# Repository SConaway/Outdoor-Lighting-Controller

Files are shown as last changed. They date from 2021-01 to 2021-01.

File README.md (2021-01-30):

# Outdoor-Lighting-Controller

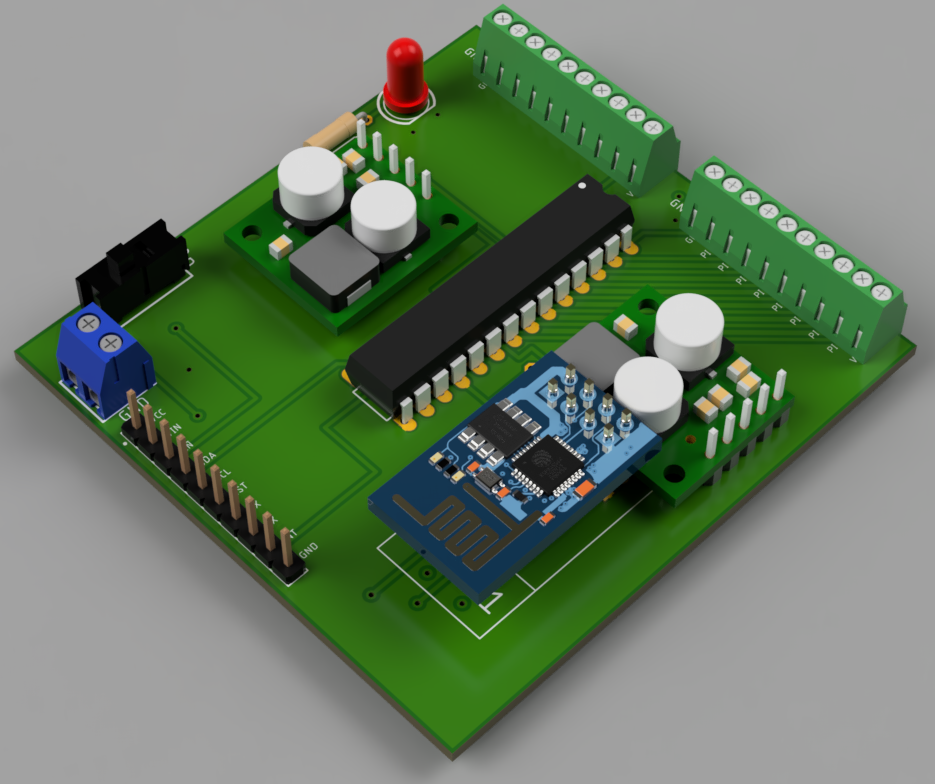
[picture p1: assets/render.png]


## Description

This is the hardware (PCB) and the software (ESPHome configuration) for a Home Assistant-based motion-lights controller. ESPHome is used to interface with Home Assistant, which is responsible for controlling the lights and motion alerts, etc.

## Instructions

1. Download the board files from GitHub Release.
2. Order the needed parts ([parts list below](#parts-list)).
    1. I used [JLCPCB](jlcpcb.com) for the PCB; it cost me $2 (+ shipping) for 5 boards.
3. Assemble all parts on the PCB.
4. [Install ESPHome](https://esphome.io/guides/getting_started_command_line.html#getting-started-with-esphome).
5. Create the secrets file from the template.
6. Connect the ESP-01 to the programming adapter.
7. Run `esphome lights.yaml compile` to compile the firmware.
8. Run `esphome lights.yaml upload` to upload the newly-compiled firmware.
9. Place the ESP-01 in the PCB, paying attention to the direction of where it points

## Parts List

-   1x Custom designed Circuit Board
-   1x 8 channel Relay Board (any generic one will work as long as it supports the needed power for your lights)
-   1x MCP23017 I2C IO Expander (**IC1**)
-   1x ESP-01 module with programmer (**U1**)
-   1x [D24V10F3 Voltage Regulator](https://www.pololu.com/product/2830) (powers ESP-01) (**VR1**)
-   1x [D24V10F5 Voltage Regulator](https://www.pololu.com/product/2831) (powers the motion sensors and MCP23017) (**VR2**)
-   _up to_ 8x PIR motion sensor
-   _up to_ 8x lights and a way to power them
    -   I used 12 Volt DC LED lights and a 120VAC --> 12VDC power supply
-   jumper wires to connect the Relay Board to the PCB (either individual wires or a 1x10 cable works)
-   2x 1x10 male header (**RELAYS and J1**)
-   1x 2x4 female header (alternatively, 2 rows of 1x4 would work too) (**socket for ESP-01**)
-   1x 2-pin 3.5mm screw terminal blocks (**J2**)
-   1x 10-pin 2.54mm (0.1 in) screw terminal blocks (**PIRS**)
-   1x SPDT on/off switch (**S1**)
-   1x 10K ohm resistor (**R1**)
-   _optional_: 1x LED (**D1**) and 1x 330 ohm resistor (**R2**)
-   1x 5K ohm resistor (I used a 5.2K ohm resistor I had lying around) (**R3**)
-   1x safe casing that prevents access to 120VAC power
-   1x server running Home Assistant for automating the lights in reaction to the motion sensors

## Notes

-   If ESPHome is not working properly (either not installing or not compiling), you can upload the binary in the GitHub Release using another uploading tool, such as `esptool`.
-   I tested this with ESPHome v1.15.3.

## [Schematics](assets/Schematic.pdf)

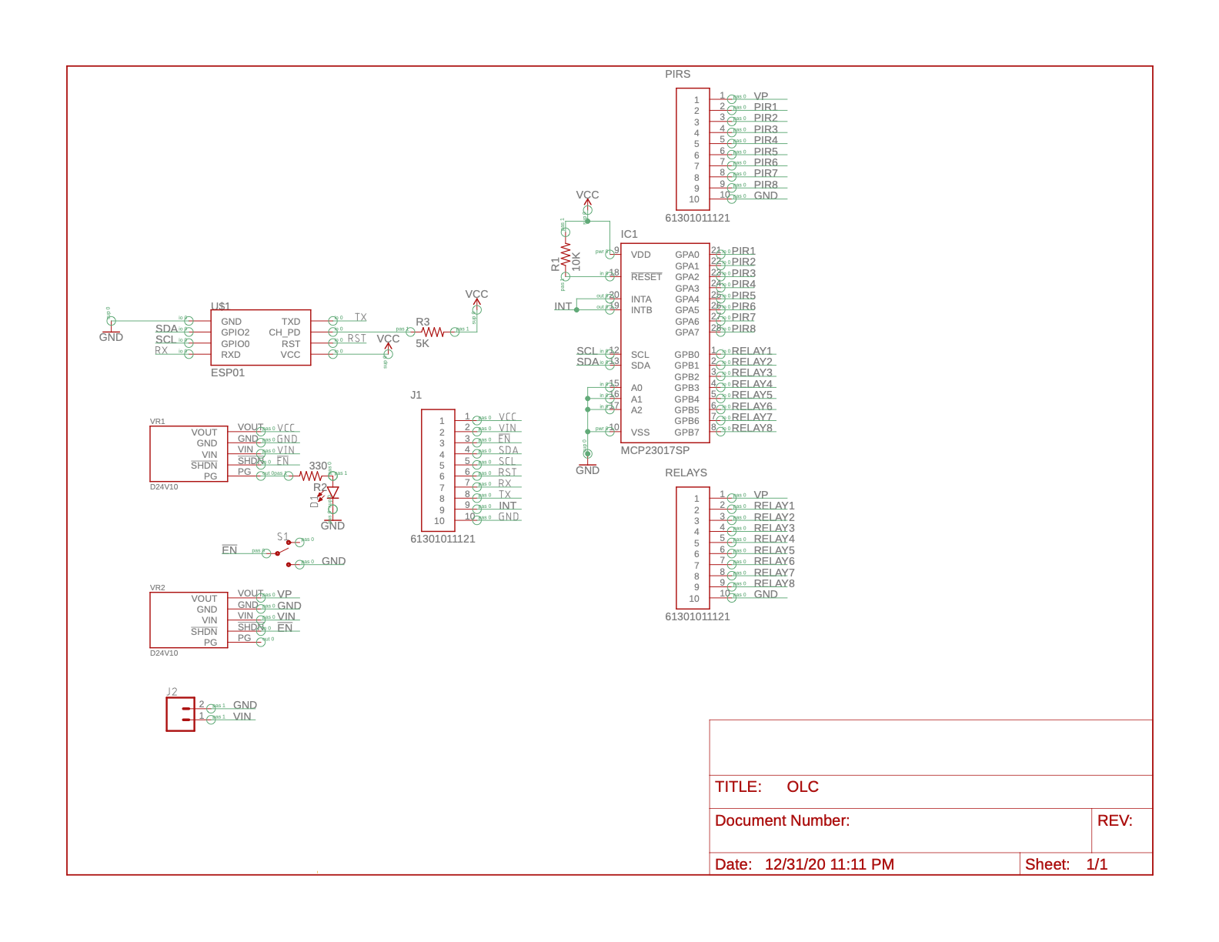
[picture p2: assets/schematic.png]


## Credits

-   [ESPHome](esphome.io)
-   [Home Assistant](home-assistant.io)
-   [Sparkfun's EAGLE libraries](https://github.com/sparkfun/SparkFun-Eagle-Libraries)

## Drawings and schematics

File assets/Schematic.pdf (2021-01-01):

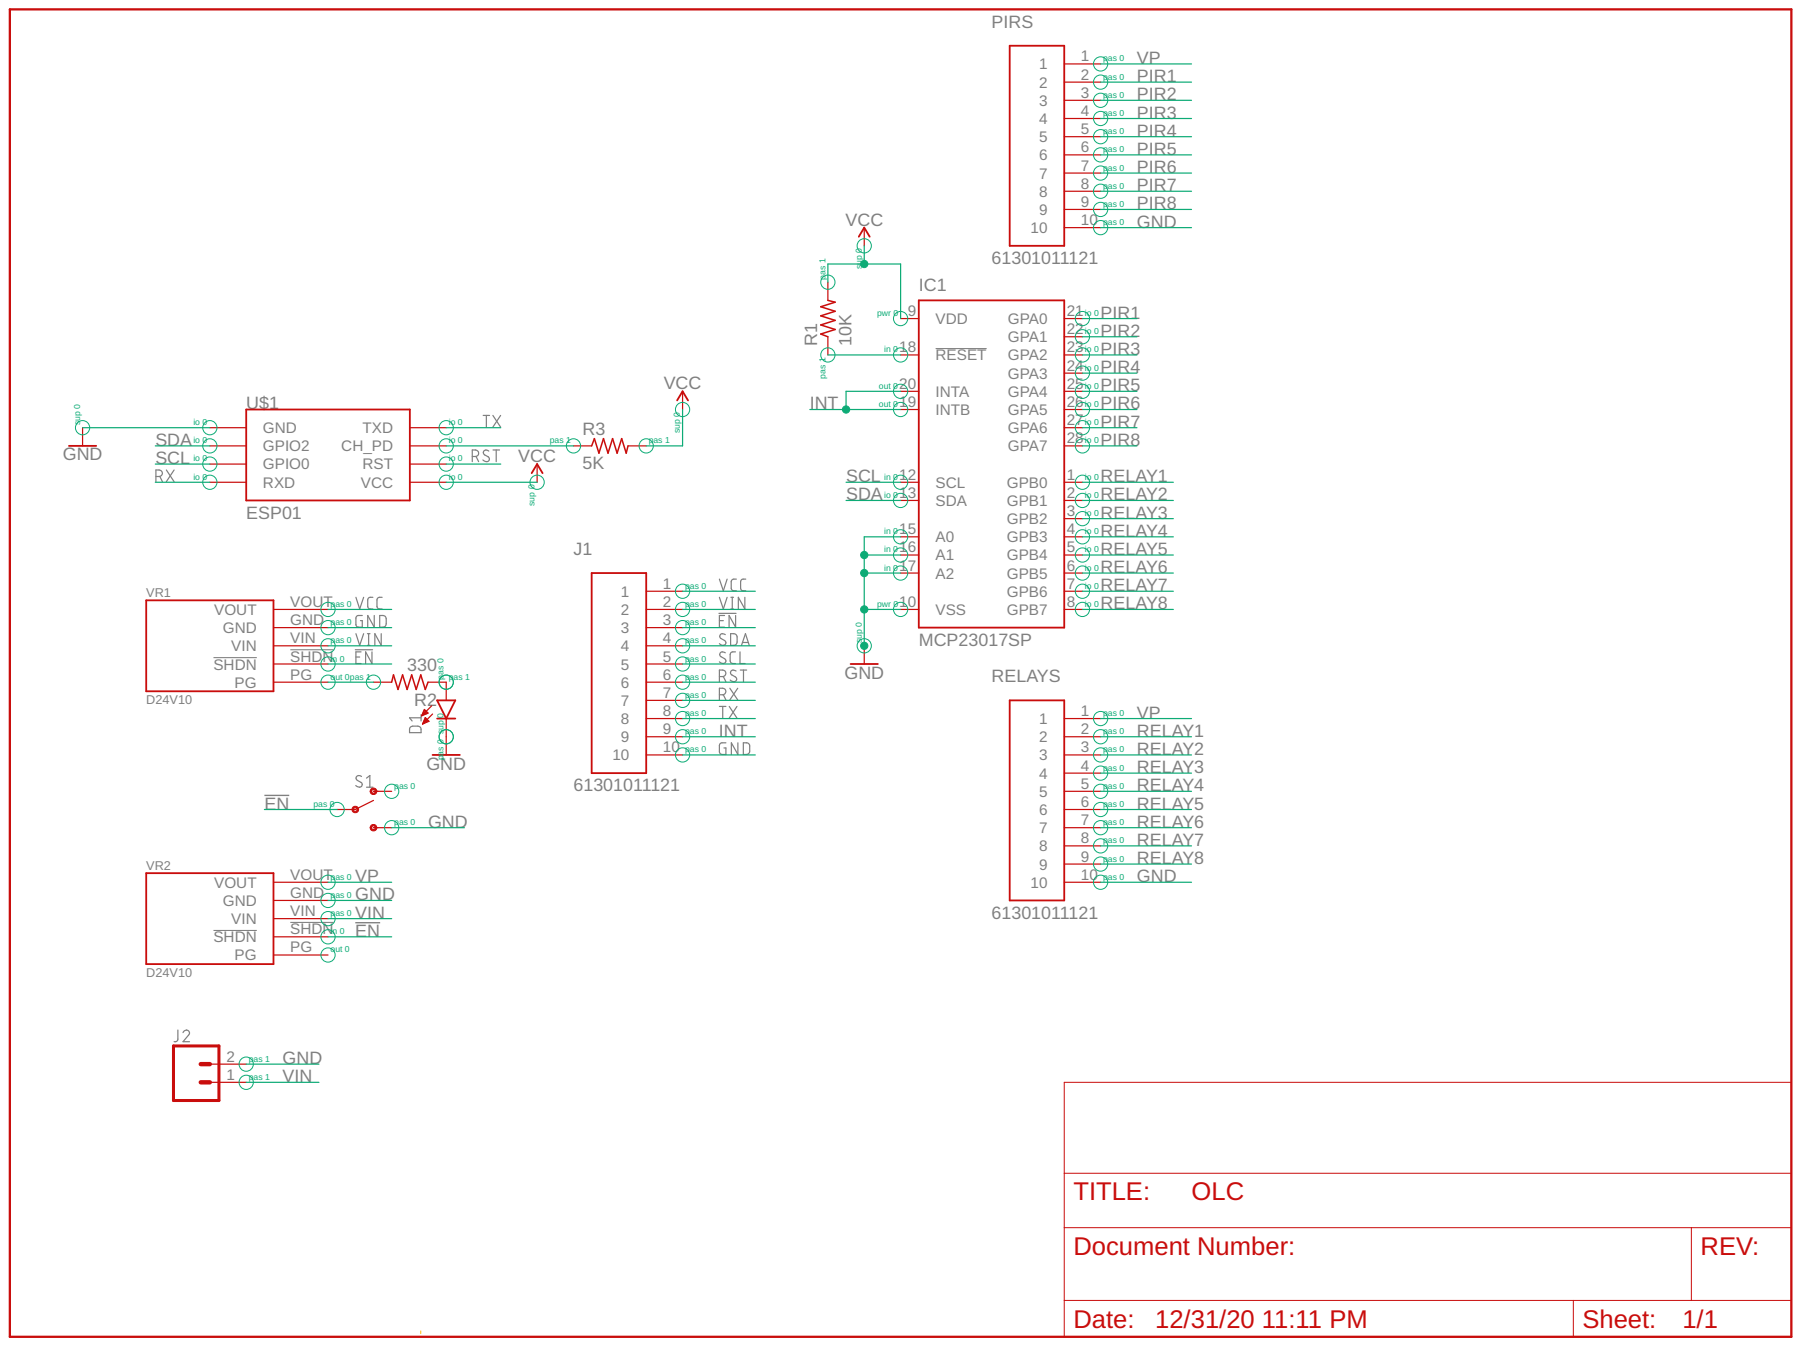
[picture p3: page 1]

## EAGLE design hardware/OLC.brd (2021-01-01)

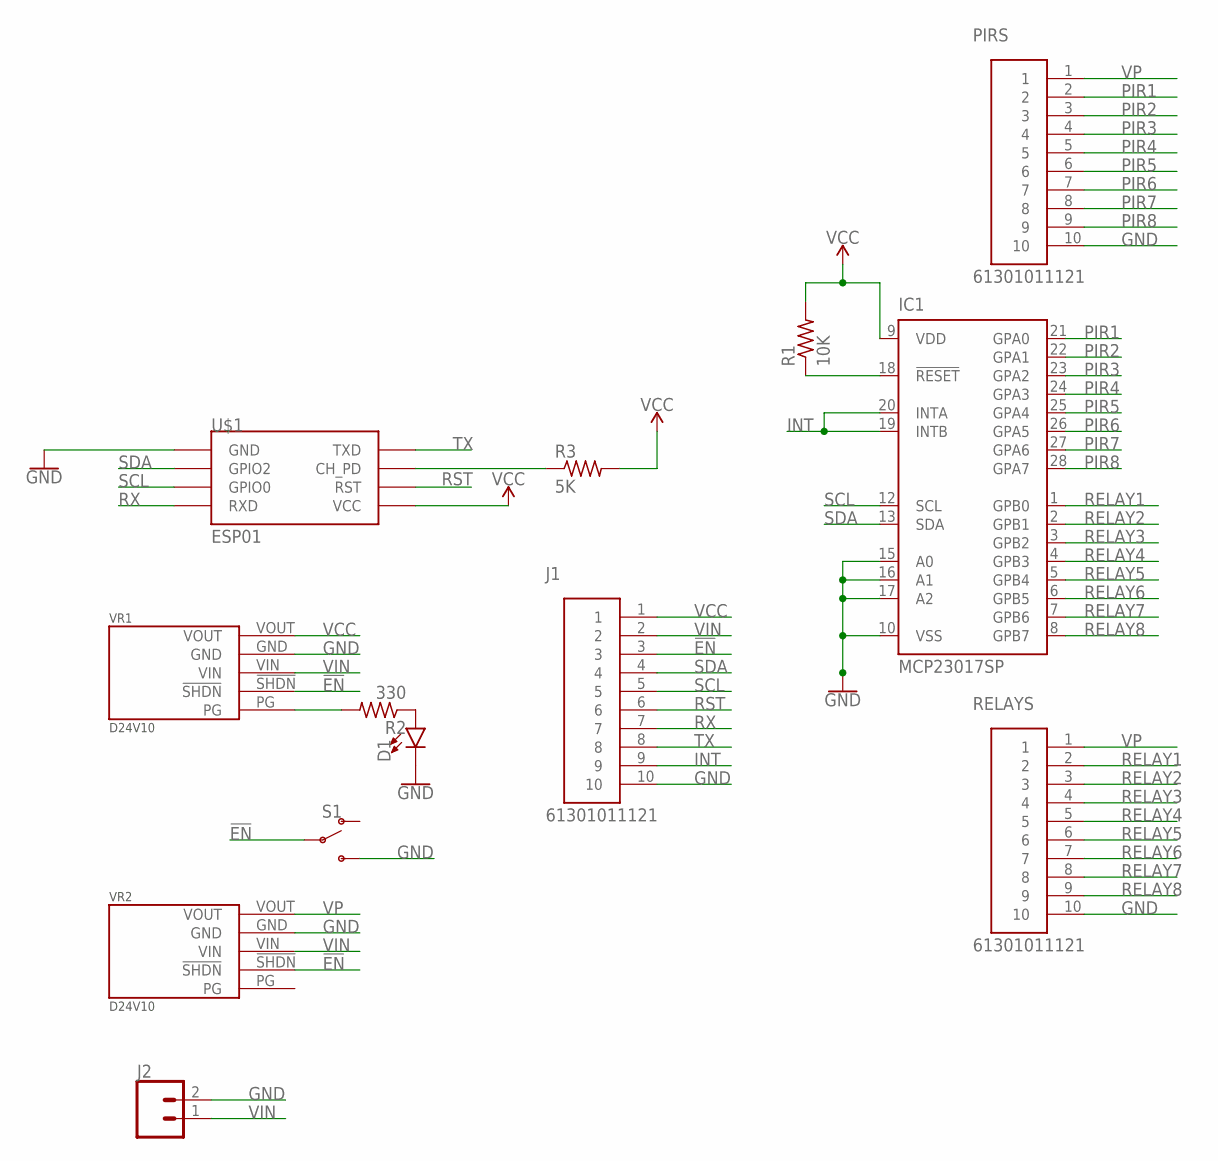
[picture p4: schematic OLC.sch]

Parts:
D1: LED5MM-KIT; LED_5MM-KIT
IC1: MCP23017SP; DIL28-3
J1: 61301011121
J2: CONN_023.5MM; SCREWTERMINAL-3.5MM-2
PIRS: 61301011121
R1: 10K; 0207/10
R2: 330; 0207/10
R3: 5K; 0207/10
RELAYS: 61301011121
S1: SWITCH-SPDT-PTH-11.6X4.0MM; SWITCH_SPDT_PTH_11.6X4.0MM
U$1: ESP01
VR1, VR2: D24V10

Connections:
!EN: J1.3, S1.2, VR1.!SHDN, VR2.!SHDN
GND: D1.K (C), IC1.10 (VSS), IC1.15 (A0), IC1.16 (A1), IC1.17 (A2), J1.10, J2.2, PIRS.10, RELAYS.10, S1.3 (S), U$1.GND, VR1.GND, VR2.GND
INT: IC1.19 (INTB), IC1.20 (INTA), J1.9
unnamed: IC1.18 (!RESET), R1.1
unnamed: D1.A, R2.1
unnamed: R2.2, VR1.PG
unnamed: R3.1, U$1.CH_PD
PIR1: IC1.21 (GPA0), PIRS.2
PIR2: IC1.22 (GPA1), PIRS.3
PIR3: IC1.23 (GPA2), PIRS.4
PIR4: IC1.24 (GPA3), PIRS.5
PIR5: IC1.25 (GPA4), PIRS.6
PIR6: IC1.26 (GPA5), PIRS.7
PIR7: IC1.27 (GPA6), PIRS.8
PIR8: IC1.28 (GPA7), PIRS.9
RELAY1: IC1.1 (GPB0), RELAYS.2
RELAY2: IC1.2 (GPB1), RELAYS.3
RELAY3: IC1.3 (GPB2), RELAYS.4
RELAY4: IC1.4 (GPB3), RELAYS.5
RELAY5: IC1.5 (GPB4), RELAYS.6
RELAY6: IC1.6 (GPB5), RELAYS.7
RELAY7: IC1.7 (GPB6), RELAYS.8
RELAY8: IC1.8 (GPB7), RELAYS.9
RST: J1.6, U$1.RST
RX: J1.7, U$1.RX (RXD)
SCL: IC1.12 (SCL), J1.5, U$1.GPIO0
SDA: IC1.13 (SDA), J1.4, U$1.GPIO2
TX: J1.8, U$1.TX (TXD)
VCC: IC1.9 (VDD), J1.1, R1.2, R3.2, U$1.VCC, VR1.VOUT
VIN: J1.2, J2.1, VR1.VIN, VR2.VIN
VP: PIRS.1, RELAYS.1, VR2.VOUT

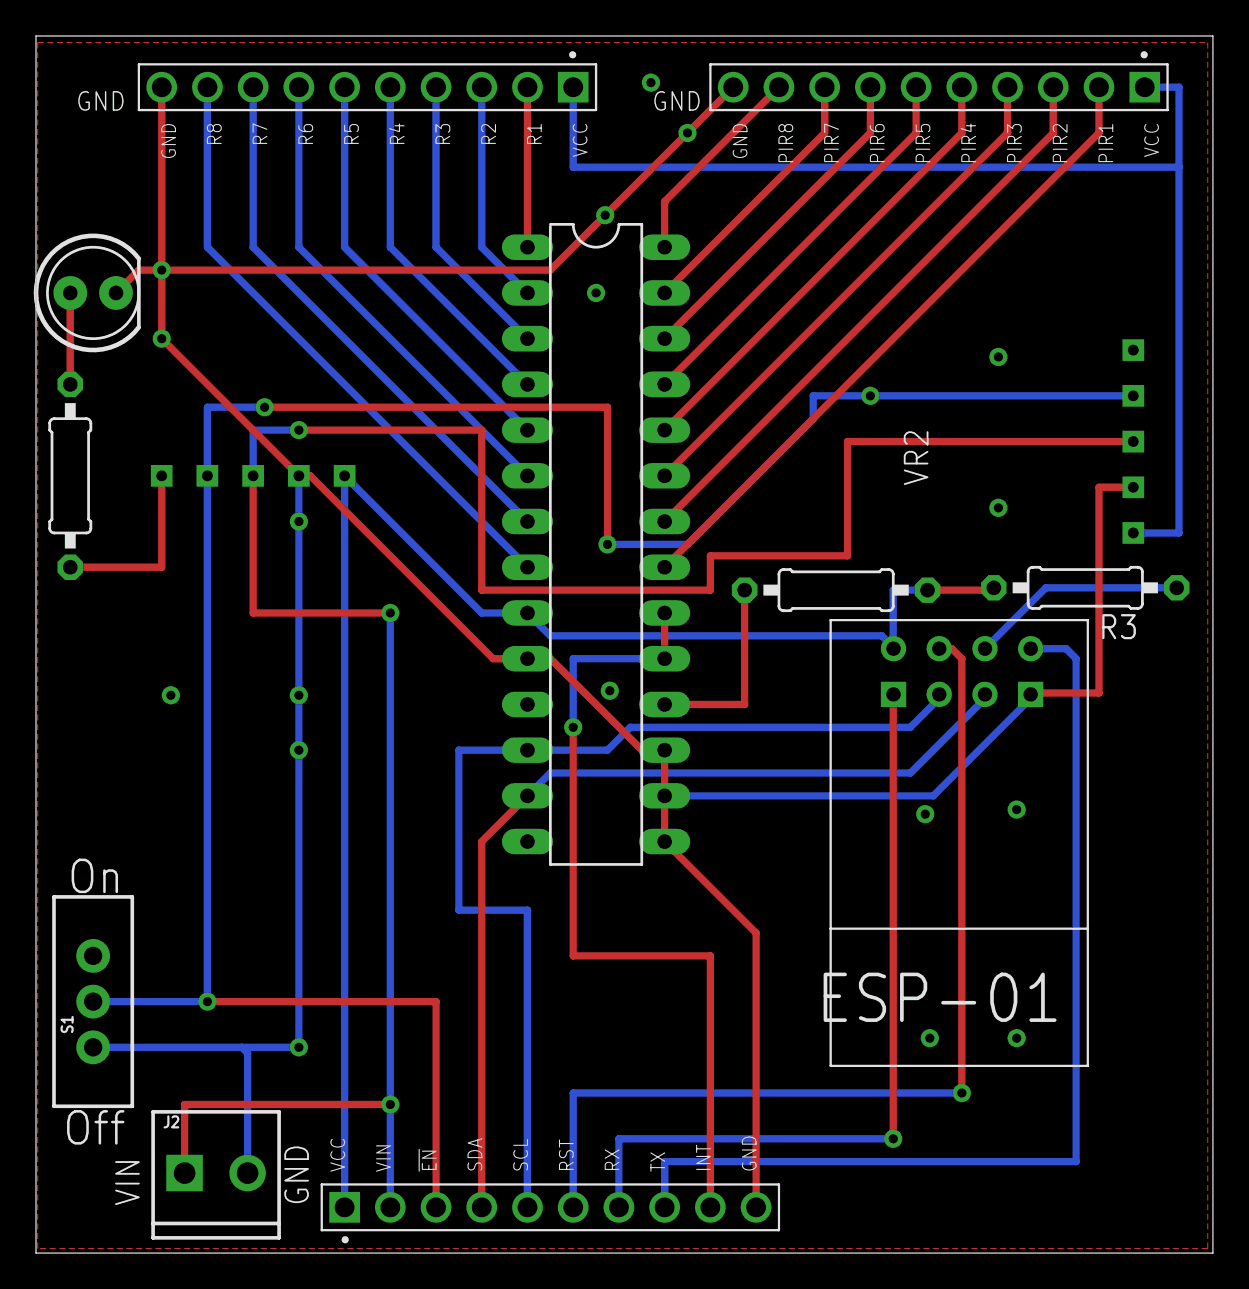
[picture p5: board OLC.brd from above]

Board: 2 copper layers, 65.4 x 67.6 mm, 13 parts (0 on the bottom side), 31 nets.

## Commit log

2021-01-01 Inital Commit
    [OLC.brd, OLC.sch]
2021-01-01 Add coming soon notice to Instructions-PCB files
2021-01-01 Add Parts List and Schematic to README
2021-01-01 Add 5K ohm resistor to parts list
2021-01-01 Add 5K ohm resistor as R3
    The ESP01 needs a pull-up resistor on CH_PD to boot, and previous designs were missing it.
    [OLC.brd, OLC.sch]

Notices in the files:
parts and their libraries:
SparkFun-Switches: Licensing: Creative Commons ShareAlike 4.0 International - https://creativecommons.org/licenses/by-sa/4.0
